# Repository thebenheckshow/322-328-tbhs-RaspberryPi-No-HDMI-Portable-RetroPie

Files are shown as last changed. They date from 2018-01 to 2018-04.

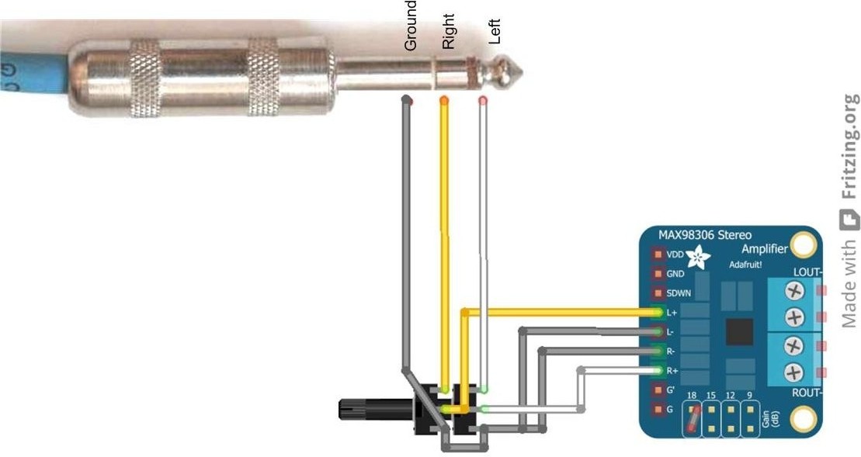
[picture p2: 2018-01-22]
Schematics/Adafruit-MAX98306-Class-D-Amp/components_Inputs.jpg

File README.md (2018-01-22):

# 322-328-tbhs-RaspberryPi-No-HDMI-Portable-RetroPie
We direct drive a TFT screen with the GPIO of a Rarspberry Pi, connect a GPIO button matrix, install RetroPie, and put it in a sleek portable game form factor.

General overview of steps:

What we did was download and install RetroPie.
Then we connected a TFT screen throught an adapter board from Adafruit.
We used 5 6 5 for the color bit depth. That is 5 bits red 6 bits green and 5 bits blue.
After connecting the screen we made a custom device tree overlay to drive the TFT screen via the GPIO connection.

Using 5 6 5 color bit depth for the TFT screen left us with exactly 8 GPIO for input.
We created a 4x4 button matrix and connected it to the GPIO.
In order to get the operating system to take input from the GPIO button matrix we needed to recompile the kernel with the GPIO button matrix kernel module enabled.
Next we created another device tree overlay to drive the GPIO button matrix.

With all the software and hardware working, Mr. Heckendorn created a sleek enclosure with a nice lasercut faceplace.

Detail of steps:

 - Compile kernel - enable GPIO matrix module

 - Create and compile device tree overlay for GPIO . . .

 - Create and compile device tree overlay for TFT . . .

 - Create a UDEV rule:

   sudo nano /etc/udev/rules.d/10-<name>.rules
   SUBSYSTEM=="input", ATTRS{name}=="<name>", ENV{ID_INPUT_KEYBOARD}="1"

. . .

References:

http://blog.gegg.us/2017/08/a-matrix-keypad-on-a-raspberry-pi-done-right/
https://github.com/adafruit/Adafruit-Retrogame
https://github.com/torvalds/linux/blob/master/include/uapi/linux/input-event-codes.h
https://www.raspberrypi.org/documentation/linux/kernel/building.md

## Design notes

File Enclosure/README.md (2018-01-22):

Enclosure

Case Design
Buttons
Faceplate

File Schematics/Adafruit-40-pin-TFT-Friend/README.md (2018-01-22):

Adafruit-40-pin-TFT-Friend
==========================

These are the Eagle CAD files for the Adafruit 40-pin TFT Friend / Breakout Board

  ---->https://www.adafruit.com/product/1932

Adafruit invests time and resources providing this open source design, please support Adafruit and open-source hardware by purchasing products from Adafruit!

Designed by Limor Fried/Ladyada for Adafruit Industries.
Creative Commons Attribution/Share-Alike, all text above must be included in any redistribution

This breakout board is something we designed in-house to help us work with 'dot-clock' 40-pin TFT displays that require the RGB pixel data to be clocked in continuously. These displays have 40-pin Flex PCB (FPC) cables and often require a boost converter for the backlight LED, which makes them annoying to breadboard. To make them breadboardable, we stuck a 40-pin FPC and a FAN5333-based backlight driver with adjustable current onto a labeled breakout board. Now you can poke and probe each pin!

The backlight driver defaults to 25mA and can boost up to 24VDC for up to 7-LED strings. Check your display datasheet for the string configuration, and short out the jumpers to increase the backlight current.

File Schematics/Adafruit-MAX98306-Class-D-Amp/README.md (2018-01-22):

# Adafruit-MAX98306-Class-D-Amp-PCB
PCB files for the Adafruit MAX98306 Class D Amp

Format is EagleCAD schematic and board layout

For more details, check out the product page at

   * https://www.adafruit.com/product/987

Adafruit invests time and resources providing this open source design, 
please support Adafruit and open-source hardware by purchasing 
products from Adafruit!

Designed by Adafruit Industries.  
Creative Commons Attribution, Share-Alike license, check license.txt for more information
All text above must be included in any redistribution

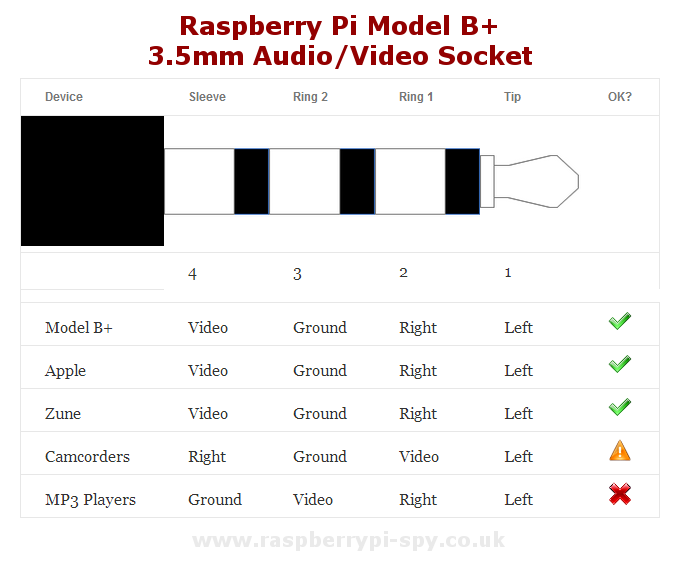
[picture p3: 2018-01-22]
Schematics/Adafruit-MAX98306-Class-D-Amp/Model-B-Plus-Audio-Video-Jack-Diagram.png

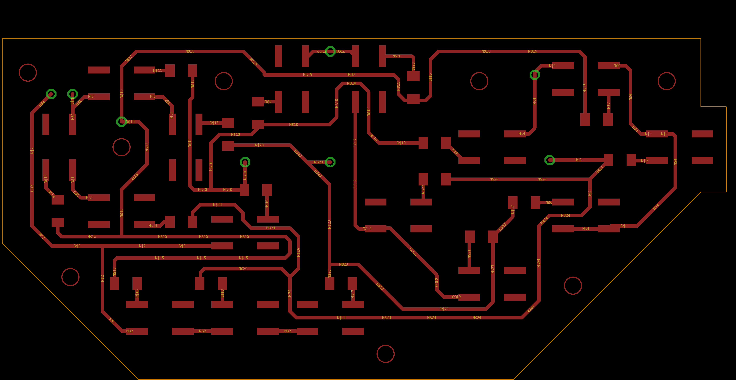
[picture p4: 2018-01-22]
Schematics/TBHS-GPIO_Button_Matrix/control_paint.png

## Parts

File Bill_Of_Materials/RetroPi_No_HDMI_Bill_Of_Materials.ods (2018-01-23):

Item No. | Component | Newark Part Number | Manufacture Part Number | Quantity | Unit Price | Total Price | URL
1 | Adafruit-40-pin-TFT-Friend | 28Y5111 | 1932 | 1 | $9.95 | $9.95 | https://www.adafruit.com/product/1932
2 | Adafruit-MAX98306-Class-D-Amp | 98Y0255 | 987 | 1 | $8.95 | $8.95 | http://www.newark.com/adafruit/987/stereo-3-7w-class-d-amplifier/dp/98Y0255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
3 | Adafruit-PowerBoost-1000C-master | 98Y0120 | 2465 | 1 | $19.95 | $19.95 | http://www.newark.com/adafruit/2465/powerboost-1000-lipo-charger-5v/dp/98Y0120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
4 | Raspberry Pi Model A, BCM2835 | 81Y5333 | RASPBRRY-MODA+-512M | 1 | $20.00 | $20.00 | http://www.newark.com/raspberry-pi/raspbrry-moda-512m/silicon-manufacturer-broadcom/dp/81Y5333
5 | 12X12WEC1 - PCB, No Holes, Single Clad | 26H0628 | 12X12WEC1 | 1 | $15.46 | $15.46 | http://www.newark.com/vector-electronics/12x12wec1/bare-pcb-no-holes-plane-single/dp/26H0628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
6 | 4.3" 40-pin TFT Display - 480x272 with Touchscreen | ---- | 1591 | 1 | $29.95 | $29.95 | https://www.adafruit.com/product/1591
7 | EVQ-Q2W03W - Tactile Switch | 53W8284 | EVQ-Q2W03W | 16 | $0.11 | $1.79 | http://www.newark.com/panasonic-electronic-components/evq-q2w03w/switch-tactile-spst-20ma-15v-pcb/dp/53W8284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
8 | Micro SD Card, 16 GB | 77Y6534 | TSRASPI10-16G | 1 | $13.99 | $13.99 | http://www.newark.com/transcend/tsraspi10-16g/memory-microsdhc-uhs-1-class-10/dp/77Y6534?st=micro%20sd%20card
9 | Screws: 2-56 Thread, 3/8" Long | ---- | 91772A079 | 6 | $0.05 | $0.28 | https://www.mcmaster.com/#91772A079
10 | Screws: 4-40 Thread, 1/4" Long | ---- | 91772A106 | 5 | $0.03 | $0.17 | https://www.mcmaster.com/#91772A106
11 | Screws: 2-56 Thread, 1/4" Long | ---- | 91772A077 | 4 | $0.04 | $0.18 | https://www.mcmaster.com/#91772A077
12 | Spray Paint | ---- | K08964000 | 1 | $7.61 | $7.61 | https://www.grainger.com/product/KRYLON-Super-MAXX-Spray-Paint-in-38EN23
13 | ROWMARK SILVER GREY 1/16" ENGRAVING PLASTIC | ---- | 321308 | 1 | $17.10 | $17.10 | https://www.johnsonplastics.com/engraving/engravable-sheet-stock/plastic/rowmark-ada-alternative-silver-grey-1-16-engraving-plastic
14 | 3D Plastic PLA – Back Shell | ---- | ---- | 1 | $0.00 | $0.00 | https://github.com/thebenheckshow/322-328-tbhs-RaspberryPi-No-HDMI-Portable-RetroPie/tree/master/Enclosure
15 | 3D Plastic PLA – Front Shell | ---- | ---- | 1 | $1.00 | $1.00 | https://github.com/thebenheckshow/322-328-tbhs-RaspberryPi-No-HDMI-Portable-RetroPie/tree/master/Enclosure
16 | 3D Plastic PLA – D-Pad | ---- | ---- | 1 | $2.00 | $2.00 | https://github.com/thebenheckshow/322-328-tbhs-RaspberryPi-No-HDMI-Portable-RetroPie/tree/master/Enclosure
17 | 3D Plastic PLA – Function Buttons | ---- | ---- | 1 | $3.00 | $3.00 | https://github.com/thebenheckshow/322-328-tbhs-RaspberryPi-No-HDMI-Portable-RetroPie/tree/master/Enclosure
18 | 3D Plastic PLA – Select Start Buttons | ---- | ---- | 1 | $4.00 | $4.00 | https://github.com/thebenheckshow/322-328-tbhs-RaspberryPi-No-HDMI-Portable-RetroPie/tree/master/Enclosure
19 | 3D Plastic PLA – ABC Buttons | ---- | ---- | 1 | $5.00 | $5.00 | https://github.com/thebenheckshow/322-328-tbhs-RaspberryPi-No-HDMI-Portable-RetroPie/tree/master/Enclosure
20 | 3D Plastic PLA – XYZ Buttons | ---- | ---- | 1 | $6.00 | $6.00 | https://github.com/thebenheckshow/322-328-tbhs-RaspberryPi-No-HDMI-Portable-RetroPie/tree/master/Enclosure
21 | Anker 4-Port USB 3.0 Ultra Slim Data Hub | ---- | A7518011_SM-A342-V01 | 1 | $9.99 | $9.99 | https://www.amazon.com/Anker-4-Port-Macbook-Surface-Notebook/dp/B00XMD7KPU
22 | Ultra ATA 2-Drive Ribbon Cable | ---- | 332781 | 1 | $5.99 | $5.99 | https://www.amazon.com/40-Pin-80-Wire-2-Drive-Ribbon-Manhattan/dp/B003IDF0JC?s=electronics
23 | Lithium Ion Polymer Battery - 3.7v 2500mAh | ---- | 328 | 1 | $14.95 | $14.95 | https://www.adafruit.com/product/328
24 | PCB Etchant Solution | 33AC2343 | CL-ETCH-16 | 1 | $12.95 | $12.95 | http://www.newark.com/caig-laboratories/cl-etch-16/pcb-etchant-solution-16oz-bottle/dp/33AC2343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
25 | SMD Chip Resistor, 33 ohm | 79M6076 | MC0805S8F330JT5E | 21 | $0.04 | $0.90 | http://www.newark.com/multicomp/mc0805s8f330jt5e/res-thick-film-33r-1-0-125w-0805/dp/79M6076?st=resistor%2033
26 | Creatology™ Adhesive Foam Sheet | ---- | M10032002 | 1 | $0.99 | $0.99 | http://www.michaels.com/creatology-adhesive-foam-sheet/M10032002.html?dwvar_M10032002_color=Black
27 | Speaker, Buzzer, Piezo, 8 ohm, 83 dB, 0 Hz to 3 kHz | 25R0795 | MCKPSP2040PN-08/0.25A-4759 | 2 | $2.03 | $4.06 | http://www.newark.com/multicomp/mckpsp2040pn-08-0-25a-4759/buzzer-piezo-850hz-83db/dp/25R0795
 |  |  |  |  | Total | $216.22

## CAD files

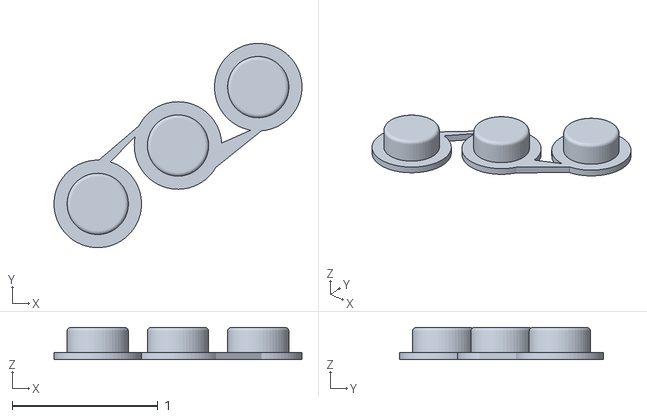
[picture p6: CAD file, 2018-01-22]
Enclosure/ABC buttons.stl
1.70 x 1.40 x 0.22

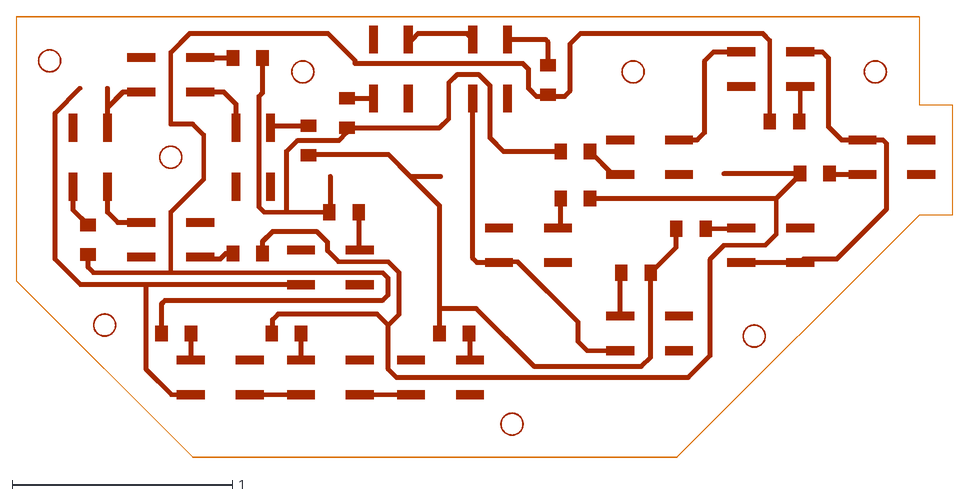
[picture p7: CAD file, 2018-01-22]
Schematics/TBHS-GPIO_Button_Matrix/controls_rev_1.dxf
4.25 x 2.00

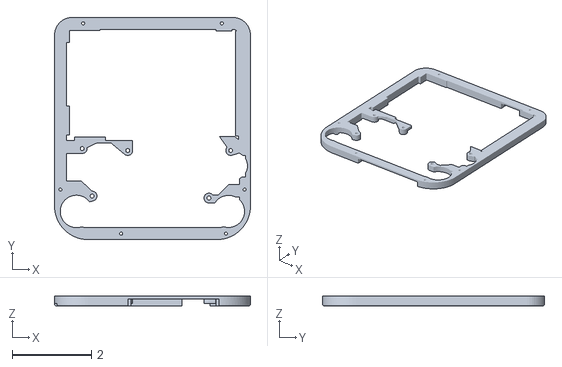
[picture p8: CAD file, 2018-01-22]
Enclosure/Front Shell.stl
4.95 x 5.61 x 0.24

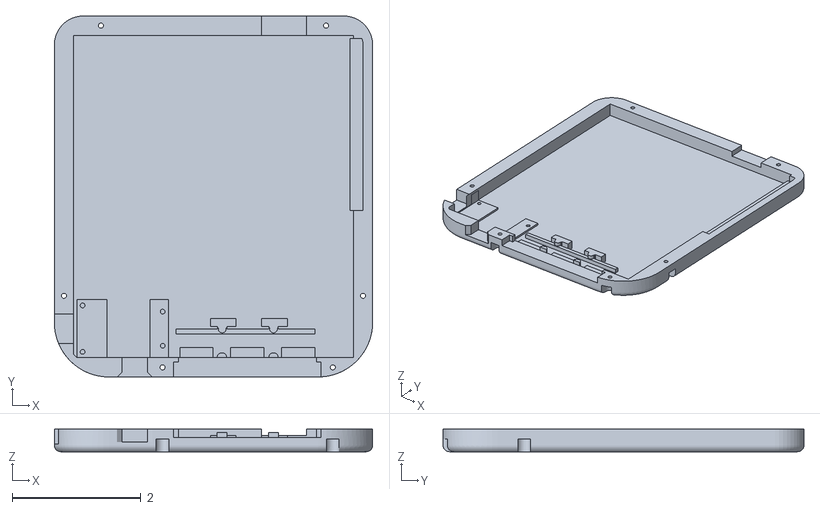
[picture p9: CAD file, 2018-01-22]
Enclosure/Back Shell.stl
4.95 x 5.61 x 0.35

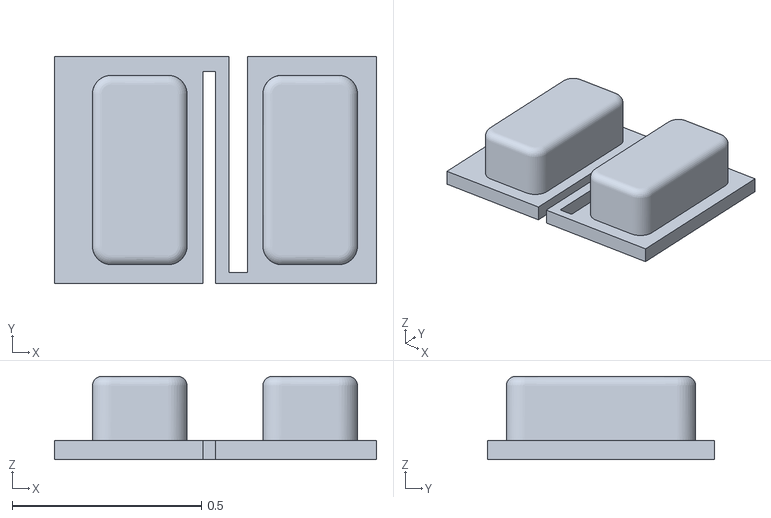
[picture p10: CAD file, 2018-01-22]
Enclosure/Select Start buttons.stl
0.85 x 0.6 x 0.22

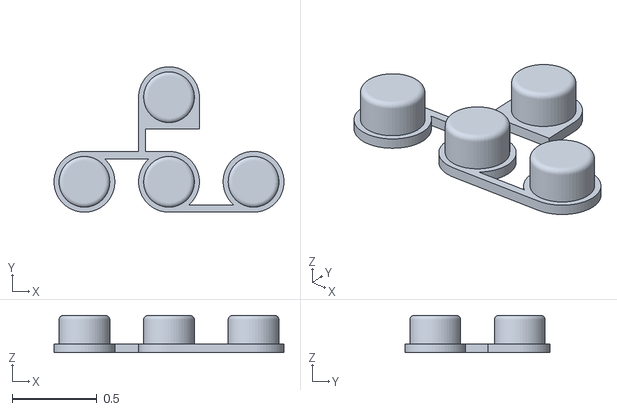
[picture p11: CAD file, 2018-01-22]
Enclosure/Function buttons.stl
1.36 x 0.86 x 0.22

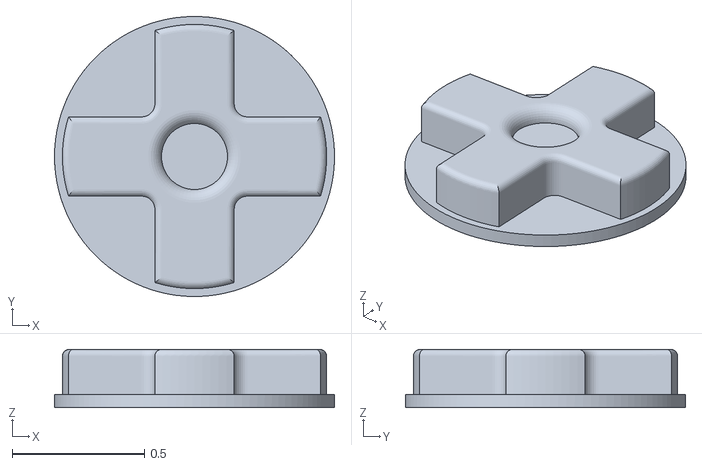
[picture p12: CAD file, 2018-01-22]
Enclosure/D-pad.stl
1.06 x 1.06 x 0.22

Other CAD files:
Enclosure/XYZ buttons.stl

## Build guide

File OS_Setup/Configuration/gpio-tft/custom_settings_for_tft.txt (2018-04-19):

# Add these lines to the config.txt -----------------------------------------------

# Disable spi and i2c, we need these pins.
dtparam=spi=off
dtparam=i2c_arm=off

# Set screen size and any overscan required
overscan_left=0
overscan_right=0
overscan_top=0
overscan_bottom=0
framebuffer_width=480
framebuffer_height=272

# enable the DPI display
enable_dpi_lcd=1
display_default_lcd=1

# set up the size to 480x272
dpi_group=2
dpi_mode=87

# set up the hsync/vsync/clock polarity and format
#dpi_output_format=520197
dpi_output_format=0x7F012

# set up the size to 480x272
hdmi_timings=480 0 40 48 88 272 0 13 3 32 0 0 0 60 0 32000000 3
gpu_mem_256=128
gpu_mem_512=256
gpu_mem_1024=256
overscan_scale=1

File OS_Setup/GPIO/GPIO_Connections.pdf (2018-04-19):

RetroPi Connections
Connection GPIO # Pin # | Pin # GPIO # Connection
3.3V | 01 | X | X | 02 | 5V
VSYNC | GPIO 02 | 03 | X | X | 04 | 5V
HSYNC | GPIO 03 | 05 | X | X | 06 | GND
B3 | GPIO 04 | 07 | X | X | 08 | GPIO 14 | G7
GND | | 09 | X | X | 10 | GPIO 15 | R3
R5 | GPIO 17 | 11 | X | X | 12 | GPIO 18 | R6
ROW_ONE | GPIO 27 | 13 | X | X | 14 | GND
ROW_ZERO | GPIO 22 | 15 | X | X | 16 | GPIO 23 | COL_ONE
3.3V | | 17 | X | X | 18 | GPIO 24 | COL_ZERO
G3 | GPIO 10 | 19 | X | X | 20 | GND
G2 | GPIO 09 | 21 | X | X | 22 | GPIO 25 | ROW_TWO
G4 | GPIO 11 | 23 | X | X | 24 | GPIO 08 | B7
GND | | 25 | X | X | 26 | GPIO 07 | B6
CLK | ID_SD | 27 | X | X | 28 | ID_SC | DE
B4 | GPIO 05 | 29 | X | X | 30 | GND
B5 | GPIO 06 | 31 | X | X | 32 | GPIO 12 | G5
G6 | GPIO 13 | 33 | X | X | 34 | GND
R7 | GPIO 19 | 35 | X | X | 36 | GPIO 16 | R4
COL_TWO | GPIO 26 | 37 | X | X | 38 | GPIO 20 | COL_THREE
GND | | 39 | X | X | 40 | GPIO 21 | ROW_THREE

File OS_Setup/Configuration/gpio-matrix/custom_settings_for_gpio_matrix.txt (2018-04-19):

# dtc -W no-unit_address_vs_reg -I dts -O dtb -o ./overlays/gpio-matrix.dtbo gpio-matrix.dts
dtoverlay=gpio-matrix

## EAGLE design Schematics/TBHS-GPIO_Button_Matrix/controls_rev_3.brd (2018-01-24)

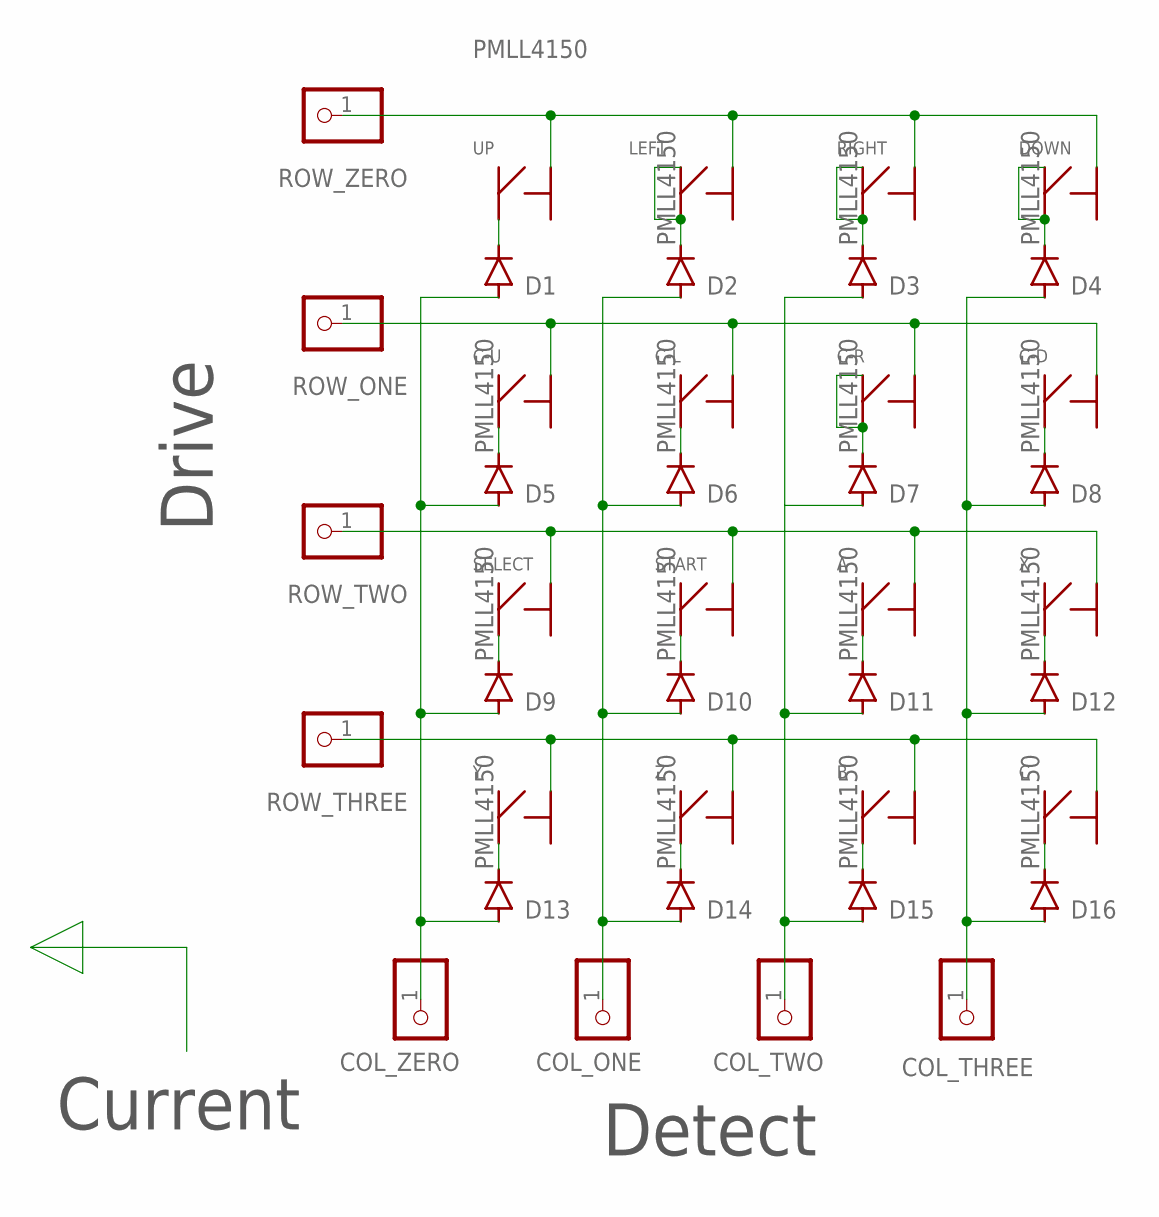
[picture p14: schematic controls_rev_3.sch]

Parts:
A: EVQQ2; TACT
B: EVQQ2; TACT
C: EVQQ2; TACT
C-D: EVQQ2; TACT
C-L: EVQQ2; TACT
C-R: EVQQ2; TACT
C-U: EVQQ2; TACT
COL_ONE: PINHD-1X1; 1X01
COL_THREE: PINHD-1X1; 1X01
COL_TWO: PINHD-1X1; 1X01
COL_ZERO: PINHD-1X1; 1X01
D1, D2, D3, D4, D5, D6, D7, D8, D9, D10, D11, D12, D13, D14, D15, D16: PMLL4150; SOD80C
DOWN: EVQQ2; TACT
LEFT: EVQQ2; TACT
RIGHT: EVQQ2; TACT
ROW_ONE: PINHD-1X1; 1X01
ROW_THREE: PINHD-1X1; 1X01
ROW_TWO: PINHD-1X1; 1X01
ROW_ZERO: PINHD-1X1; 1X01
SELECT: EVQQ2; TACT
START: EVQQ2; TACT
UP: EVQQ2; TACT
X: EVQQ2; TACT
Y: EVQQ2; TACT
Z: EVQQ2; TACT

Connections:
1: D1.C, UP.PIN0@0 (PIN0)
COL_ONE: COL_ONE.1, D2.A, D6.A, D10.A, D14.A
COL_THREE: COL_THREE.1, D4.A, D8.A, D12.A, D16.A
COL_TWO: COL_TWO.1, D3.A, D7.A, D11.A, D15.A
COL_ZERO: COL_ZERO.1, D1.A, D5.A, D9.A, D13.A
unnamed: D9.C, SELECT.PIN0@0 (PIN0)
unnamed: C-U.PIN0@0 (PIN0), D5.C
unnamed: D10.C, START.PIN0@0 (PIN0)
unnamed: D12.C, X.PIN0@0 (PIN0)
unnamed: B.PIN0@0 (PIN0), D15.C
unnamed: D14.C, Z.PIN0@0 (PIN0)
unnamed: D13.C, Y.PIN0@0 (PIN0)
unnamed: A.PIN0@0 (PIN0), D11.C
unnamed: C.PIN0@0 (PIN0), D16.C
unnamed: D2.C, LEFT.PIN0@0 (PIN0), LEFT.PIN0@1 (PIN0)
unnamed: D3.C, RIGHT.PIN0@0 (PIN0), RIGHT.PIN0@1 (PIN0)
unnamed: D4.C, DOWN.PIN0@0 (PIN0), DOWN.PIN0@1 (PIN0)
unnamed: C-L.PIN0@0 (PIN0), D6.C
unnamed: C-R.PIN0@0 (PIN0), C-R.PIN0@1 (PIN0), D7.C
unnamed: C-D.PIN0@0 (PIN0), D8.C
ROW_ONE: C-D.PIN1@1 (PIN1), C-L.PIN1@1 (PIN1), C-R.PIN1@1 (PIN1), C-U.PIN1@1 (PIN1), ROW_ONE.1
ROW_THREE: B.PIN1@1 (PIN1), C.PIN1@1 (PIN1), ROW_THREE.1, Y.PIN1@1 (PIN1), Z.PIN1@1 (PIN1)
ROW_TWO: A.PIN1@1 (PIN1), ROW_TWO.1, SELECT.PIN1@1 (PIN1), START.PIN1@1 (PIN1), X.PIN1@1 (PIN1)
ROW_ZERO: DOWN.PIN1@1 (PIN1), LEFT.PIN1@1 (PIN1), RIGHT.PIN1@1 (PIN1), ROW_ZERO.1, UP.PIN1@1 (PIN1)

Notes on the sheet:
Drive
Detect
Current

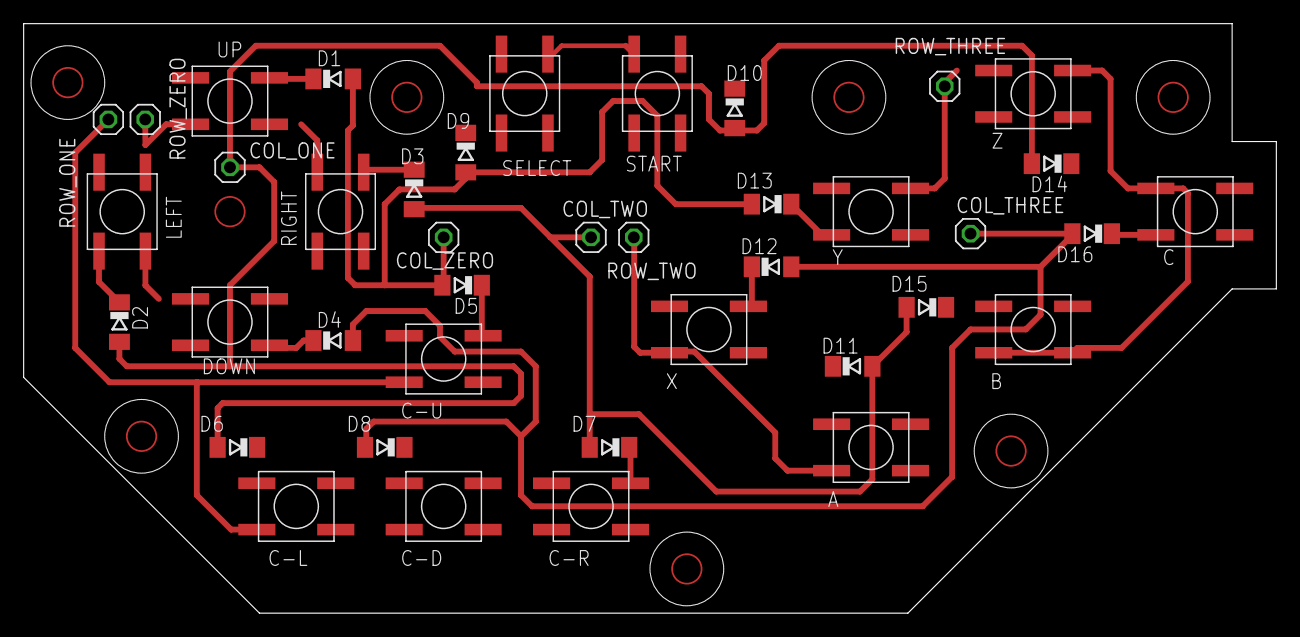
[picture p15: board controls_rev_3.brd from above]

Board: 2 copper layers, 108.0 x 50.8 mm, 40 parts (0 on the bottom side), 24 nets.

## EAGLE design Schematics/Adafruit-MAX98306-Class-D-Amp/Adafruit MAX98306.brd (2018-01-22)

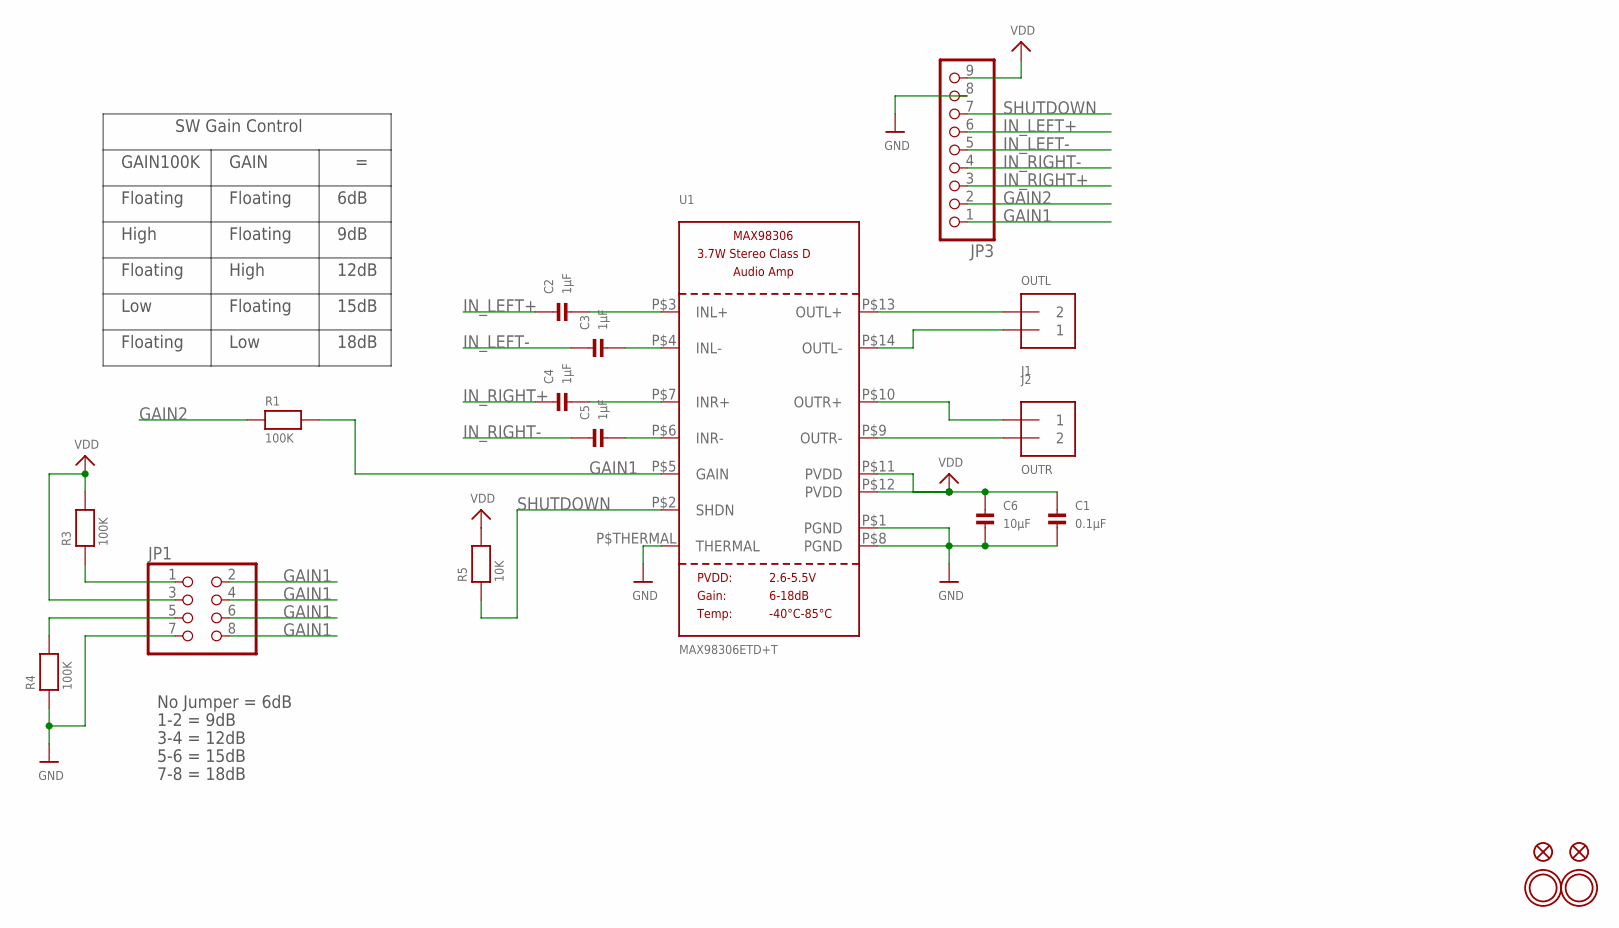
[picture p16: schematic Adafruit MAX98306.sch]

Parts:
C1: 0.1µF; 0805
C2, C3, C4, C5: 1µF; 0805
C6: 10µF; 0805
FID1, FID2: FIDUCIAL""; FIDUCIAL_1MM
J1: OUTL; TERMBLOCK_1X2-3.5MM
J2: OUTR; TERMBLOCK_1X2-3.5MM
JP1: PINHD-2X4; 2X04
JP3: HEADER-1X970MIL; 1X09_ROUND_70
R1, R3, R4: 100K; 0805
R5: 10K; 0805
U1: MAX98306ETD+T; TDFN14_3X3MM
U$6, U$7: MOUNTINGHOLE2.5; MOUNTINGHOLE_2.5_PLATED

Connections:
GAIN1: JP1.2, JP1.4, JP1.6, JP1.8, JP3.1, R1.2, U1.P$5 (GAIN)
GAIN2: JP3.2, R1.1
GND: C1.2, C6.2, JP1.7, JP3.8, R4.1, U1.P$1 (PGND), U1.P$8 (PGND), U1.P$THERMAL (THERMAL)
IN_LEFT+: C2.1, JP3.6
IN_LEFT-: C3.1, JP3.5
IN_RIGHT+: C4.1, JP3.3
IN_RIGHT-: C5.1, JP3.4
LOUT-: J1.1, U1.P$14 (OUTL-)
unnamed: JP1.1, R3.1
unnamed: C2.2, U1.P$3 (INL+)
unnamed: JP1.5, R4.2
unnamed: C3.2, U1.P$4 (INL-)
unnamed: C4.2, U1.P$7 (INR+)
unnamed: C5.2, U1.P$6 (INR-)
unnamed: J1.2, U1.P$13 (OUTL+)
unnamed: J2.2, U1.P$9 (OUTR-)
ROUT+: J2.1, U1.P$10 (OUTR+)
SHUTDOWN: JP3.7, R5.1, U1.P$2 (SHDN)
VDD: C1.1, C6.1, JP1.3, JP3.9, R3.2, R5.2, U1.P$11 (PVDD), U1.P$12 (PVDD)

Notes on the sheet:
GAIN100K
GAIN
Floating
6dB
High
9dB
12dB
Low
15dB
18dB
SW Gain Control
No Jumper = 6dB
1-2 = 9dB
3-4 = 12dB
5-6 = 15dB
7-8 = 18dB

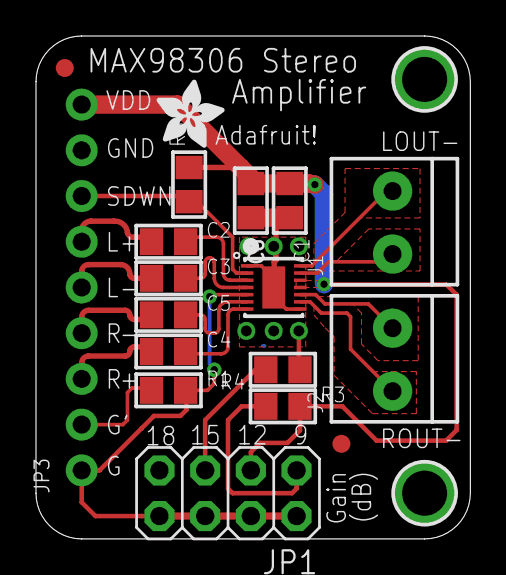
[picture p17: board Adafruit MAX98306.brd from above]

Board: 2 copper layers, 24.1 x 27.9 mm, 20 parts (0 on the bottom side), 19 nets.

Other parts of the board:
U$10: ADAFRUIT_3.5MM

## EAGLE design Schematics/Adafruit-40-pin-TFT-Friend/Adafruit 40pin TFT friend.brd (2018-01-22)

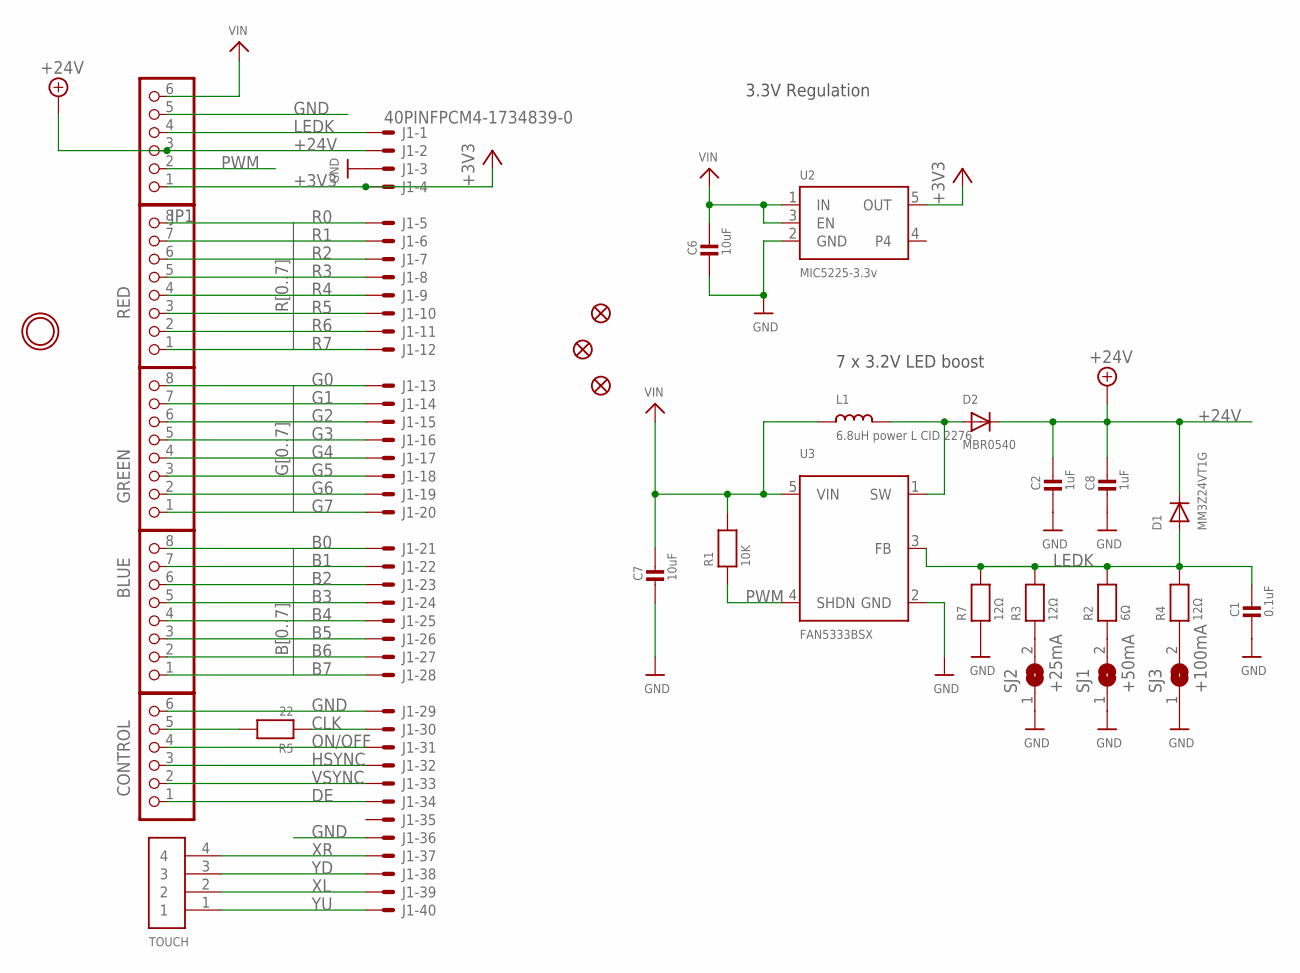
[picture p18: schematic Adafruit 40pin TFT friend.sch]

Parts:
BLUE: PINHD-1X8BIG; 1X08-BIG
C1: 0.1uF; _0805MP
C2, C8: 1uF; _0805MP
C6, C7: 10uF; _0805MP
CONTROL: PINHD-1X6B; 1X06-BIG
D1: MM3Z24VT1G; SMADIODE
D2: MBR0540; SOD-123
FID1, FID2, FID3: FIDUCIAL""; FIDUCIAL_1MM
GREEN: PINHD-1X8BIG; 1X08-BIG
J1: 40PINFPCM4-1734839-0; 4-1734839-0
JP1: PINHD-1X6B; 1X06-BIG
L1: 6.8uH power L CID 2276; INDUCTOR_5X5MM_NR5040_NOTHERMALS
R1: 10K; _0805MP
R2: 6Ω; _0805MP
R3, R4, R7: 12Ω; _0805MP
R5: 22; _0805MP
RED: PINHD-1X8BIG; 1X08-BIG
SJ1: +50mA; SOLDERJUMPER_ARROW_NOPASTE
SJ2: +25mA; SOLDERJUMPER_ARROW_NOPASTE
SJ3: +100mA; SOLDERJUMPER_ARROW_NOPASTE
TOUCH: 1X4-BIG; 1X04-BIG
U2: MIC5225-3.3v; SOT23-5
U3: FAN5333BSX; SOT23-5@1
U$7: MOUNTINGHOLE2.5; MOUNTINGHOLE_2.5_PLATED

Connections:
+3V3: J1.4 (MS), JP1.1, U2.5 (OUT)
+24V: C2.1, C8.1, D1.C, D2.C, J1.2 (MS), JP1.3
B0: BLUE.8, J1.21 (MS)
B1: BLUE.7, J1.22 (MS)
B2: BLUE.6, J1.23 (MS)
B3: BLUE.5, J1.24 (MS)
B4: BLUE.4, J1.25 (MS)
B5: BLUE.3, J1.26 (MS)
B6: BLUE.2, J1.27 (MS)
B7: BLUE.1, J1.28 (MS)
CLK: J1.30 (MS), R5.1
DE: CONTROL.1, J1.34 (MS)
G0: GREEN.8, J1.13 (MS)
G1: GREEN.7, J1.14 (MS)
G2: GREEN.6, J1.15 (MS)
G3: GREEN.5, J1.16 (MS)
G4: GREEN.4, J1.17 (MS)
G5: GREEN.3, J1.18 (MS)
G6: GREEN.2, J1.19 (MS)
G7: GREEN.1, J1.20 (MS)
GND: C1.2, C2.2, C6.2, C7.2, C8.2, CONTROL.6, J1.3 (MS), J1.29 (MS), J1.36 (MS), JP1.5, R7.1, SJ1.1, SJ2.1, SJ3.1, U2.2 (GND), U3.2 (GND)
HSYNC: CONTROL.3, J1.32 (MS)
LEDK: C1.1, D1.A, J1.1 (MSV), JP1.4, R2.2, R3.2, R4.2, R7.2, U3.3 (FB)
unnamed: R2.1, SJ1.2
unnamed: R3.1, SJ2.2
unnamed: R4.1, SJ3.2
unnamed: CONTROL.5, R5.2
unnamed: D2.A, L1.P$2 (2), U3.1 (SW)
ON/OFF: CONTROL.4, J1.31 (MS)
PWM: JP1.2, R1.1, U3.4 (SHDN)
R0: J1.5 (MS), RED.8
R1: J1.6 (MS), RED.7
R2: J1.7 (MS), RED.6
R3: J1.8 (MS), RED.5
R4: J1.9 (MS), RED.4
R5: J1.10 (MS), RED.3
R6: J1.11 (MS), RED.2
R7: J1.12 (MS), RED.1
VIN: C6.1, C7.1, JP1.6, L1.P$1 (1), R1.2, U2.1 (IN), U2.3 (EN), U3.5 (VIN)
VSYNC: CONTROL.2, J1.33 (MS)
XL: J1.39 (MS), TOUCH.2
XR: J1.37 (MS), TOUCH.4
YD: J1.38 (MS), TOUCH.3
YU: J1.40 (MS), TOUCH.1

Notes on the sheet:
7 x 3.2V LED boost
3.3V Regulation

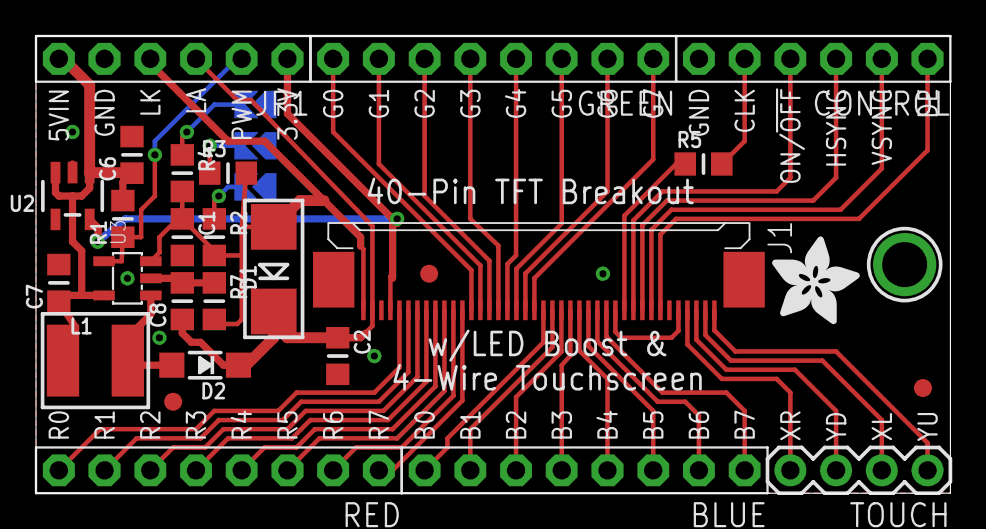
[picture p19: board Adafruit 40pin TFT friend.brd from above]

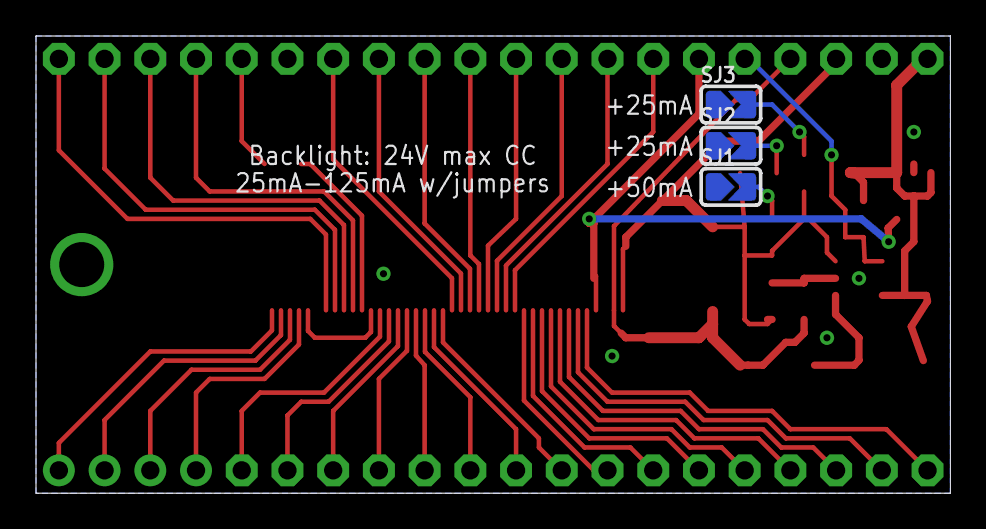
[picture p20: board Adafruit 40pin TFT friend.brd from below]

Board: 2 copper layers, 50.8 x 25.4 mm, 31 parts (3 on the bottom side), 44 nets.

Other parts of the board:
U$15: ADAFRUIT_5MM

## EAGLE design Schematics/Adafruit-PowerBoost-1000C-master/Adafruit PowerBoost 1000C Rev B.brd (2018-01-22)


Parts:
B1: JST 2-PH; JSTPH2
C1, C7, C8: 10uF; 0805-NO
C2: 2.2uF; 0805-NO
C4: 0.1uF; 0805_10MGAP
C6: 100uF; C1210
CHRG/LBO: ORANGE; CHIPLED_0805_NOOUTLINE
CN1: USBA_FEMALE; USB_HOST-PTH
CN4: MicroUSB; 4UCONN_20329
DONE: GREEN; CHIPLED_0805_NOOUTLINE
FID1, FID2, FID3: FIDUCIAL""; FIDUCIAL_1MM
JP2: HEADER-1X8ROUND; 1X08_ROUND
L1: 6.8uH; INDUCTOR_5X5MM_TDK_VLC5045
LED1: RED; CHIPLED_0805_NOOUTLINE
LED2: BLUE; CHIPLED_0805_NOOUTLINE
R1: 1.87M; _0805MP
R2: 340K; _0805MP
R3: 1.87M; 0805-NO
R4, R13: 200K; 0805-NO
R5, R8, R14, R20: 1K; 0805-NO
R6: 270K; 0805-NO
R7, R17: 100K; 0805-NO
R9: 43K; 0805-NO
R10: 49.9K; 0805-NO
R11: 75K 1%; 0805-NO
R12: 49.9K 1%; 0805-NO
R16: 1.0K; 0805-NO
T1: MMUN2133LT1G; SC59-BEC
THERM: 15K; 0805-NO
U1: TPS61090RSAR; PVQFN-16
U2: MCP73871; QFN20_4MM
U$10, U$11: MOUNTINGHOLE2.5; MOUNTINGHOLE_2.5_PLATED
X1: TERMBLOCK_1X2; TERMBLOCK_1X2-3.5MM

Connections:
5.0V: C2.1, C6.1, CN1.VBUS, JP2.8, R3.2, R5.1, R9.2, R11.2, U1.1 (VOUT), U1.15 (VOUT), U1.16 (VOUT), X1.2
D+: CN1.D+, R11.1, R12.1
D-: CN1.D-, R9.1, R10.1
ENABLE: JP2.4, R13.2, U1.11 (EN)
GND: B1.1 (-), C1.2, C2.2, C4.2, C6.2, C7.2, C8.2, CN1.GND, CN4.BASE@1 (GND), CN4.BASE@2 (GND), CN4.GND, CN4.SPRT@1 (GND), CN4.SPRT@2 (GND), CN4.SPRT@3 (GND), CN4.SPRT@4 (GND), JP2.5, JP2.7, LED1.C, LED2.C, R2.1, R4.1, R7.2, R10.2, R12.2, R16.1, R17.1, THERM.1, U1.5 (PGND), U1.6 (PGND), U1.7 (PGND), U1.10 (SYNC), U1.13 (GND), U1.P$18 (PGND), U1.P$19 (PGND), U1.P$20 (PGND), U1.P$21 (PGND), U1.P$22 (PGND), U1.THERMAL (PGND), U2.P$10 (VSS1), U2.P$11 (VSS2), U2.P$21 (THERMAL), X1.1
LBO: JP2.6, T1.B, U1.12 (LBO)
unnamed: L1.P$2 (2), U1.3 (SW), U1.4 (SW)
unnamed: LED1.A, R20.1
unnamed: R1.1, R2.2, U1.9 (LBI)
unnamed: LED2.A, R5.2
unnamed: R3.1, R4.2, U1.14 (FB)
unnamed: R20.2, T1.C
unnamed: R6.1, R7.1, U2.P$2 (VPCC)
unnamed: DONE.C, R14.2
unnamed: R14.1, U2.P$7 (STAT2)
unnamed: THERM.2, U2.P$5 (THERM)
unnamed: R8.1, U2.P$8 (STAT1/LBO)
unnamed: CHRG/LBO.C, R8.2
unnamed: R17.2, U2.P$12 (PROG3)
unnamed: R16.2, U2.P$13 (PROG1)
VBAT: C1.1, C4.1, JP2.3, L1.P$1 (1), R1.2, R13.1, T1.E, U1.8 (VBAT), U2.P$1 (VOUT1), U2.P$20 (VOUT2)
VBUS: C8.1, CHRG/LBO.A, CN4.VBUS, DONE.A, JP2.1, R6.2, U2.P$3 (SEL), U2.P$4 (PROG2), U2.P$9 (/TE), U2.P$17 (CE), U2.P$18 (VIN1), U2.P$19 (VIN2)
VLIPO: B1.2 (+), C7.1, JP2.2, U2.P$14 (VBAT1), U2.P$15 (VBAT2), U2.P$16 (VBATSENS)

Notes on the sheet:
Both grounds must be connected on the PCB at only one point close to the GND pin.
On/Off Switch
See Pg 15 1st para
6.8uH power w/2A current
R3 = 1.9Mohm for 5.2V R3 = 1.1Mohm for 3.3V
Charge Rate = 1000V/PROG1
1.0K = 1000mA
2.0K = 500mA
No Thermistor:
10K NTC Thermistor:
RT1 = 0, RT2 = 10K
RT1 = TBD, RT2 = TBD



Board: 2 copper layers, 36.1 x 22.9 mm, 47 parts (2 on the bottom side), 23 nets.

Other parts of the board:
U$12: PCBFEAT-REV-040
U$25: SYMBOL_PLUS
U$26: SYMBOL_MINUS
U$28: ADAFRUIT_5MM
U$45: ADAFRUIT_3.5MM

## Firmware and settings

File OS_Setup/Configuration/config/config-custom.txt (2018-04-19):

# For more options and information see
# http://rpf.io/configtxtreadme Some settings may
# impact device functionality. See link above for
# details

# Boot with custom kernel
kernel=kernel-gpio-matrix.img

# uncomment if you get no picture on HDMI for a default "safe" mode
#hdmi_safe=1

# uncomment this if your display has a black border of unused pixels visible
# and your display can output without overscan
#disable_overscan=1

# uncomment the following to adjust overscan. Use positive numbers if console
# goes off screen, and negative if there is too much border
#overscan_left=16
#overscan_right=16
#overscan_top=16
#overscan_bottom=16

# uncomment to force a console size. By default it will be display's size minus
# overscan.
#framebuffer_width=1280
#framebuffer_height=720

# uncomment if hdmi display is not detected and composite is being output
#hdmi_force_hotplug=1

# uncomment to force a specific HDMI mode (this will force VGA)
#hdmi_group=1
#hdmi_mode=1

# uncomment to force a HDMI mode rather than DVI. This can make audio work in
# DMT (computer monitor) modes
#hdmi_drive=2

# uncomment to increase signal to HDMI, if you have interference, blanking, or
# no display
#config_hdmi_boost=4

# uncomment for composite PAL
#sdtv_mode=2

#uncomment to overclock the arm. 700 MHz is the default.
#arm_freq=800

# Uncomment some or all of these to enable the optional hardware interfaces
#dtparam=i2c_arm=on
#dtparam=i2s=on
#dtparam=spi=on

# Uncomment this to enable the lirc-rpi module
#dtoverlay=lirc-rpi

# Additional overlays and parameters are documented /boot/overlays/README

# Enable audio (loads snd_bcm2835)
dtparam=audio=on
gpu_mem=256
enable_uart=0

#NEW STUFF-----------------------------------------------

# Disable spi and i2c, we need these pins.
dtparam=spi=off
dtparam=i2c_arm=off

# Set screen size and any overscan required
overscan_left=0
overscan_right=0
overscan_top=0
overscan_bottom=0
framebuffer_width=480
framebuffer_height=272

# enable the DPI display
enable_dpi_lcd=1
display_default_lcd=1

# set up the size to 480x272
dpi_group=2
dpi_mode=87

# set up the hsync/vsync/clock polarity and format
#dpi_output_format=520197
dpi_output_format=0x7F012

# set up the size to 480x272
hdmi_timings=480 0 40 48 88 272 0 13 3 32 0 0 0 60 0 32000000 3
gpu_mem_256=128
gpu_mem_512=256
gpu_mem_1024=256
overscan_scale=1

# dtc -W no-unit_address_vs_reg -I dts -O dtb -o ./overlays/gpio-matrix.dtbo gpio-matrix.dts
dtoverlay=gpio-matrix

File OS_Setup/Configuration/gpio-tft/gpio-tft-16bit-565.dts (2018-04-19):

/dts-v1/;

// Compile with the following script:
//#! /bin/bash
//echo "sudo dtc -I dts -O dtb -o /boot/dt-blob.bin gpio-tft-16bit-565.dts"
//sudo dtc -I dts -O dtb -o /boot/dt-blob.bin gpio-tft-16bit-565.dts


/ {
   videocore {
      pins_rev1 {
         pin_config {
            pin@default {
               polarity = "active_high";
               termination = "pull_down";
               startup_state = "inactive";
               function = "input";
            }; // pin
            pin@p2  { function = "i2c1";   termination = "pull_up"; }; // I2C 1 SDA
            pin@p3  { function = "i2c1";   termination = "pull_up"; }; // I2C 1 SCL
            pin@p5  { function = "output"; termination = "pull_down"; }; // CAM_LED
            pin@p6  { function = "output"; termination = "pull_down"; }; // LAN NRESET
            pin@p14 { function = "uart0";  termination = "no_pulling"; drive_strength_mA = < 8 >; }; // TX uart0
            pin@p15 { function = "uart0";  termination = "pull_up"; drive_strength_mA = < 8 >; }; // RX uart0
            pin@p16 { function = "output"; termination = "pull_up"; polarity="active_low"; }; // activity LED
            pin@p27 { function = "output"; termination = "no_pulling";    }; // Camera shutdown
            pin@p40 { function = "pwm";    termination = "no_pulling"; drive_strength_mA = < 16 >; }; // Left audio
            pin@p45 { function = "pwm";    termination = "no_pulling"; drive_strength_mA = < 16 >; }; // Right audio
            pin@p46 { function = "input";  termination = "no_pulling";    }; // Hotplug
            pin@p47 { function = "input";  termination = "no_pulling";    }; // SD_CARD_DETECT
            pin@p48 { function = "sdcard"; termination = "pull_up";    drive_strength_mA = < 8 >; }; // SD CLK
            pin@p49 { function = "sdcard"; termination = "pull_up";    drive_strength_mA = < 8 >; }; // SD CMD
            pin@p50 { function = "sdcard"; termination = "pull_up";    drive_strength_mA = < 8 >; }; // SD D0
            pin@p51 { function = "sdcard"; termination = "pull_up";    drive_strength_mA = < 8 >; }; // SD D1
            pin@p52 { function = "sdcard"; termination = "pull_up";    drive_strength_mA = < 8 >; }; // SD D2
            pin@p53 { function = "sdcard"; termination = "pull_up";    drive_strength_mA = < 8 >; }; // SD D3
         }; // pin_config

         pin_defines {
            pin_define@HDMI_CONTROL_ATTACHED {
               type = "internal";
               number = <46>;
            };
            pin_define@NUM_CAMERAS {
               type = "internal";
               number = <1>;
            };
            pin_define@CAMERA_0_UNICAM_PORT {
               type = "internal";
               number = <1>;
            };
            pin_define@CAMERA_0_I2C_PORT {
               type = "internal";
               number = <1>;
            };
            pin_define@CAMERA_0_SDA_PIN {
               type = "internal";
               number = <2>;
            };
            pin_define@CAMERA_0_SCL_PIN {
               type = "internal";
               number = <3>;
            };
            pin_define@CAMERA_0_SHUTDOWN {
               type = "internal";
               number = <27>;
            };
            pin_define@CAMERA_0_LED {
               type = "internal";
               number = <5>;
            };
            pin_define@FLASH_0_ENABLE {
               type = "absent";
            };
            pin_define@FLASH_0_INDICATOR {
               type = "absent";
            };
            pin_define@FLASH_1_ENABLE {
               type = "absent";
            };
            pin_define@FLASH_1_INDICATOR {
               type = "absent";
            };
            pin_define@POWER_LOW {
               type = "absent";
            };
            pin_define@LEDS_DISK_ACTIVITY {
               type = "internal";
               number = <16>;
            };
            pin_define@LAN_RUN {
               type = "internal";
               number = <6>;
            };
            pin_define@SMPS_SDA {
               type = "absent";
            };
            pin_define@SMPS_SCL {
               type = "absent";
            };
            pin_define@ETH_CLK {
               type = "absent";
            };
            pin_define@USB_LIMIT_1A2 {
               type = "absent";
            };
            pin_define@SIO_1V8_SEL {
               type = "absent";
            };
            pin_define@PWML {
               type = "internal";
               number = <40>;
            };
            pin_define@PWMR {
               type = "internal";
               number = <45>;
            };
            pin_define@SAFE_MODE {
               type = "internal";
               number = <1>;
            };
            pin_define@SD_CARD_DETECT {
               type = "internal";
               number = <47>;
            };
            pin_define@ID_SDA {
               type = "absent";
            };
            pin_define@ID_SCL {
               type = "absent";
            };
            pin_define@DISPLAY_I2C_PORT {
               type = "internal";
               number = <0>;
            };
            pin_define@DISPLAY_SDA {
               type = "internal";
               number = <0>;
            };
            pin_define@DISPLAY_SCL {
               type = "internal";
               number = <1>;
            };
         }; // pin_defines
      }; // pins_rev1
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

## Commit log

2018-01-22 Add schematic for A+
2018-01-22 Add schematics
    [Adafruit 40pin TFT friend.brd, Adafruit 40pin TFT friend.sch, Adafruit MAX98306.brd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]
2018-01-22 Add case design files.
    [ABC buttons.stl, Back Shell.stl, D-pad.stl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]
2018-01-23 Update bill of materials.
    [RetroPi_No_HDMI_Bill_Of_Materials.ods]
2018-01-24 Update bill of schematic.
    [controls_rev_2.sch]
2018-01-24 Update schematic.
    [controls_rev_3.brd, controls_rev_3.sch]
2018-04-19 Update setup files.
    [GPIO_Connections.ods, config-custom.txt, config-default.txt]

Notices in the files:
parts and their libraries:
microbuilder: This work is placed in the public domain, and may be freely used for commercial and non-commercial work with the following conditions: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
